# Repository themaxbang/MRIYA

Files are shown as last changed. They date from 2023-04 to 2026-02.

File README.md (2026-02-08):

# MRIYA
**MRIYA** (Ukrainian for «Dream») is a 42-key column-staggered split keyboard based on [Corne Cherry v.3.0.1](https://github.com/foostan/crkbd)

MRIYA

## Features
- Design optimized for wireless
- Updated thumb cluster (inspired by [Jian](https://github.com/KGOH/Jian-Info))
- Reset buttons
- Native nice!view support
- Updated column stagger
- 3DP bumper case (inspired by [Dao Choc BLE](https://github.com/yumagulovrn/dao-choc-ble))
- CNC plates
- BSI-10H Slide Switches
- Molex PicoBlade 1.25mm connectors
- LiPo Battery 301230/301645 support
- No-Solder Spring Headers support
- No LEDs
- Hotswap MX
- ZMK support

## PCB
<table align="center">
    <tr>
        <td align="left">Software</td>
        <td align="left"><a href="https://www.kicad.org/">KiCad 9.0.7 Stable</a></td>
    </tr>
    <tr>
        <td align="left">Silkscreen font</td>
        <td align="left"><a href="https://fonts.google.com/specimen/Roboto">Roboto</a> | <a href="https://fonts.google.com/specimen/Roboto+Condensed">Roboto condensed</a></td>
    </tr>
    <tr>
        <td align="left">Bird logo</td>
        <td align="left"><a href="https://pngtree.com/freepng/minimalist-bird-logo_4124682.html">pngtree.com</a></td>
    </tr>
    <tr>
        <td align="left">PCB Art</td>
        <td align="left"> Olga Rai <a href="https://www.shutterstock.com/g/OlgaRai">Shutterstock</a> | <a href="https://stock.adobe.com/contributor/209778624/olga-rai">Adobe Stock</a></td>
    </tr>
</table>

#### <div align="center">Top<div>
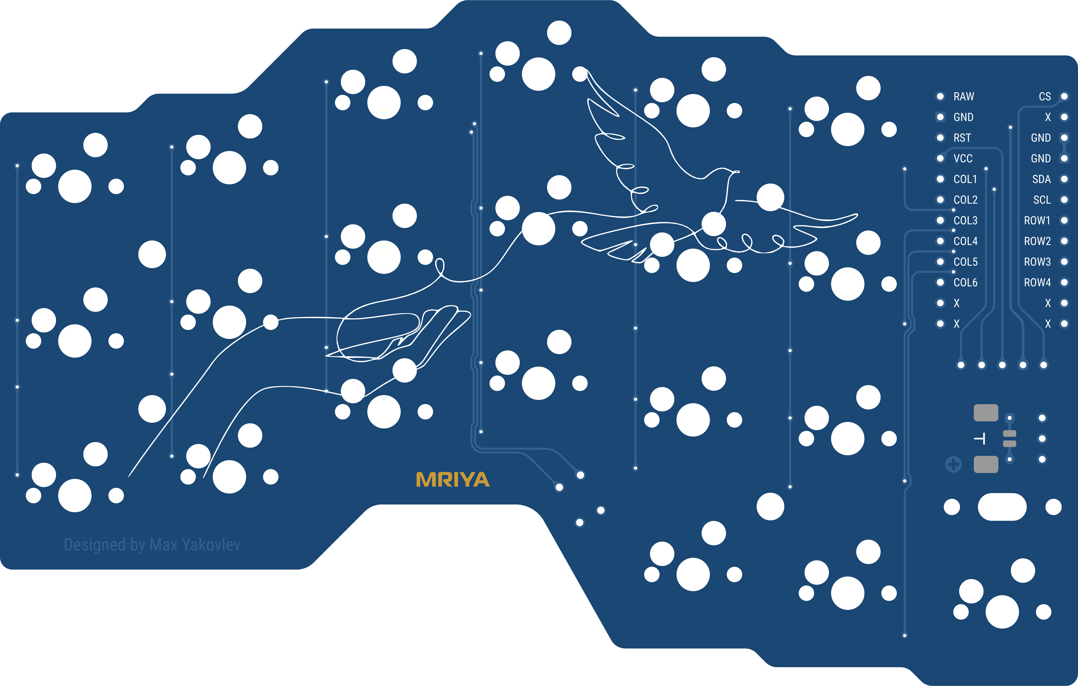
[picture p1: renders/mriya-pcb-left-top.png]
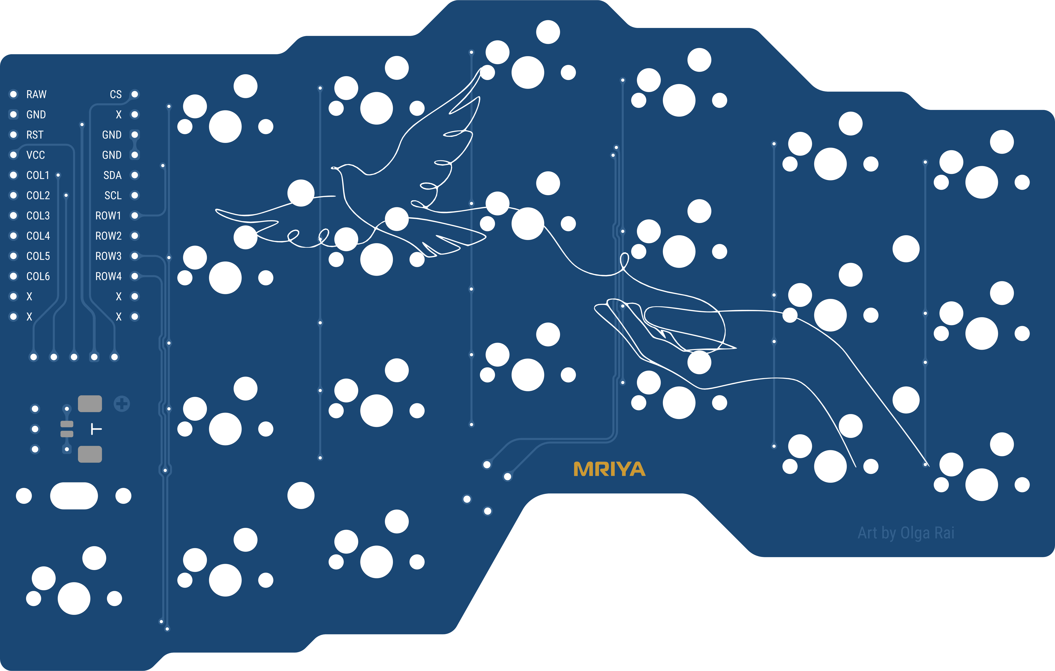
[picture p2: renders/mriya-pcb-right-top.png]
| 
 ---- | -----  

#### <div align="center">Bottom<div>
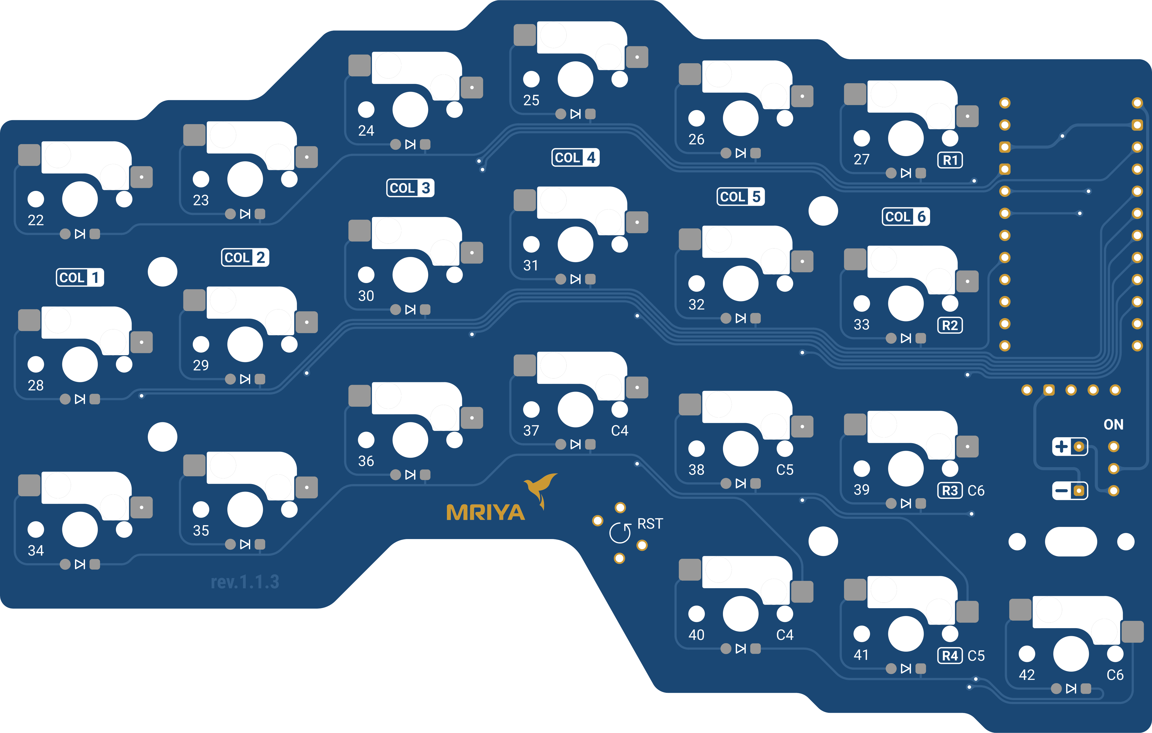
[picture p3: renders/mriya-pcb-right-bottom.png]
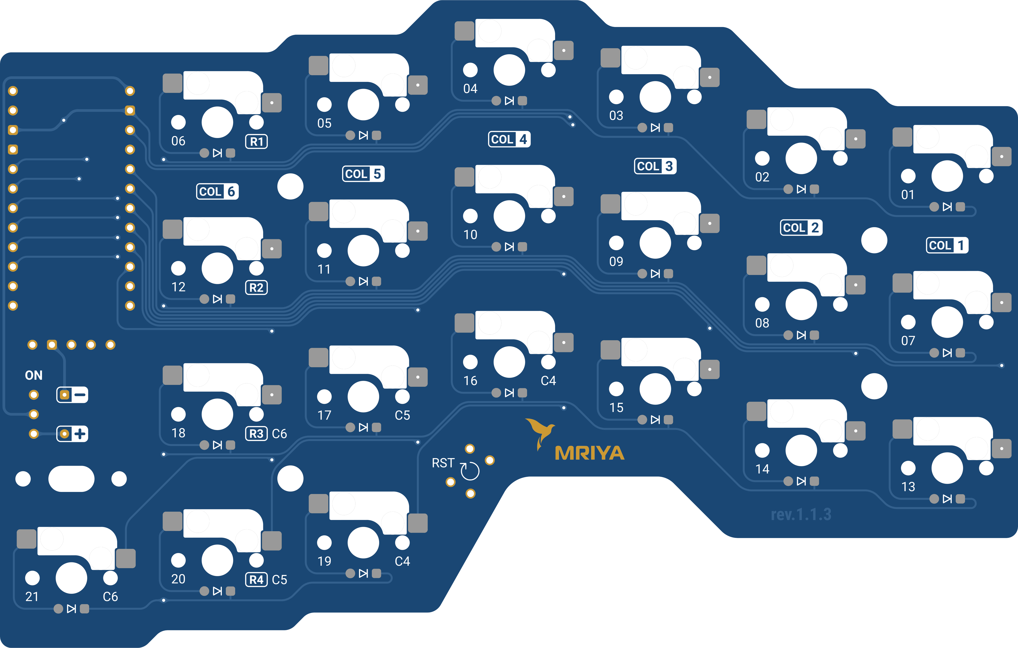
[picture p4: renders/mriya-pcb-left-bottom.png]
|   
 ---- | -----  

## PCB Plates
<table align="center">
    <tr>
        <td align="left">Logo font</td>
        <td align="left"><a href="https://fontbundles.net/integritype-studio/1610789-william-narasi-calligraphy-font">William Narasi</a></td>
    </tr>
</table>

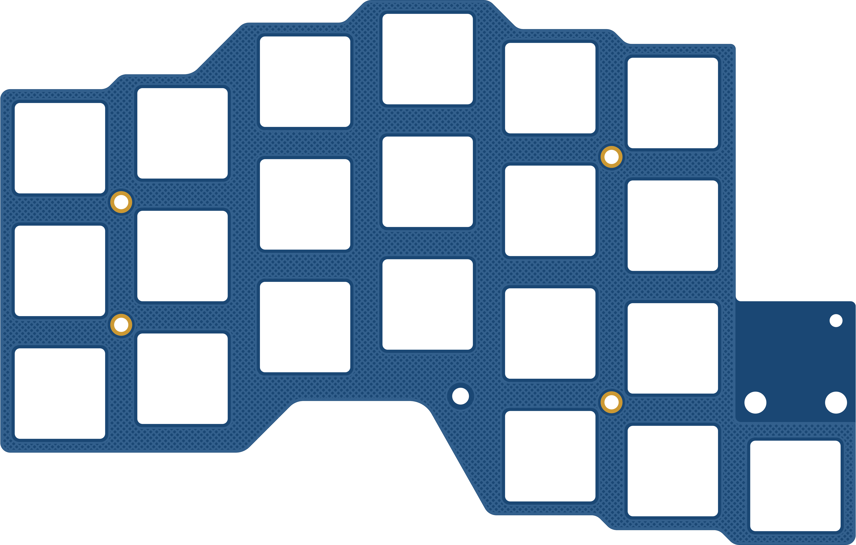
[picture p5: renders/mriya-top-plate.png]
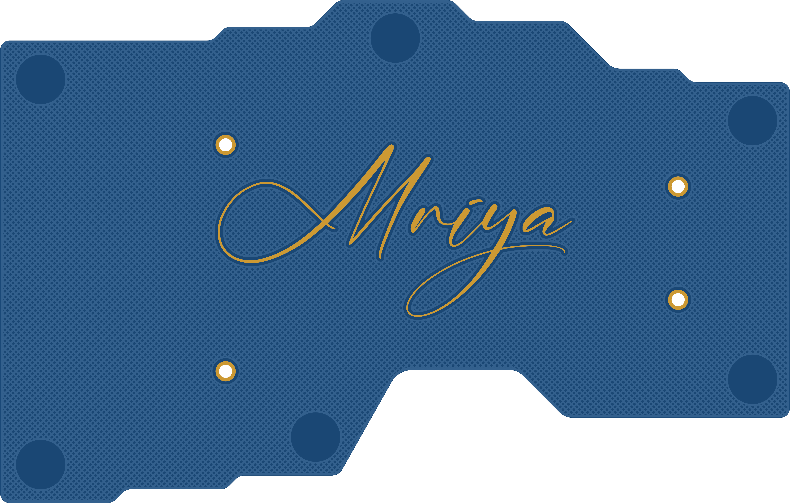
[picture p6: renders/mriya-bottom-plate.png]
|   
 ---- | -----

## 3D Printed Bumper Case
#### <div align="center">FDM<div>
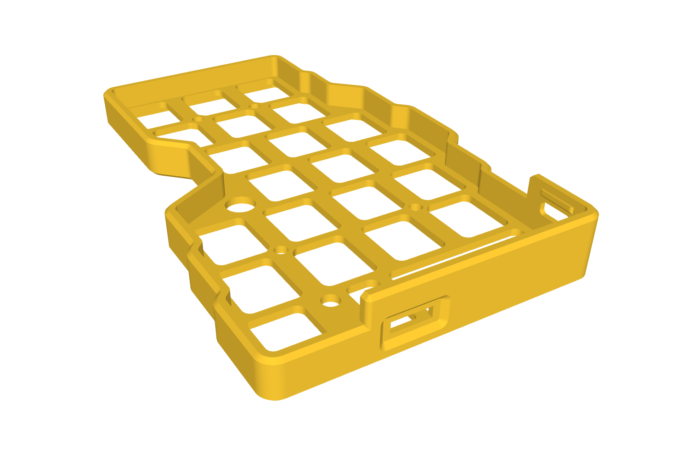
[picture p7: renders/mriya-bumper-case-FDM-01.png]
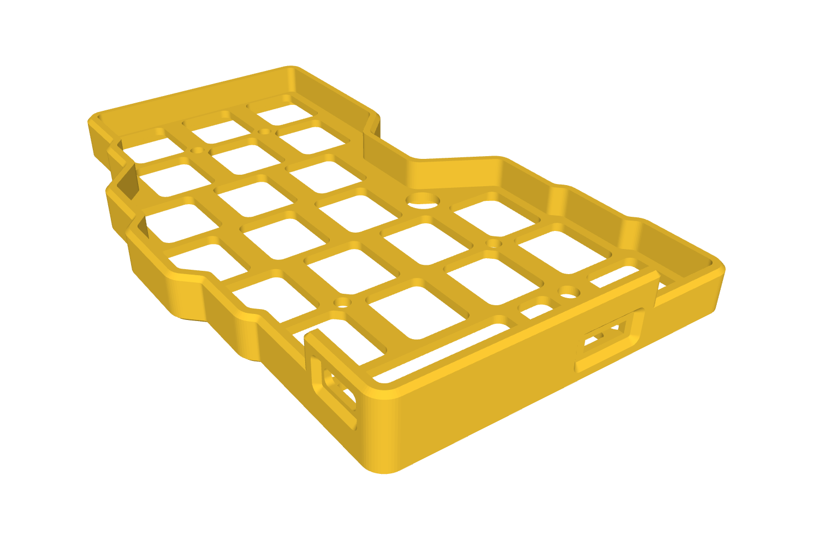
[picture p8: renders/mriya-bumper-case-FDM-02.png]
|
 ---- | -----

## Bill of Materials
Reference|Name|Qty|LCSC|AliExpess
 ------- | ------- | ------- | ------- | ------- 
U1, U2 | Microcontroller: [nRFMicro](https://github.com/joric/nrfmicro) / SuperMini nRF52840 / nice!nano | 2 | --- | [AliExpress](https://aliexpress.com/item/1005006282506884.html?sku_id=12000036599296319)
SW1-SW42 | Kailh Hotswap Socket CPG151101S11 | 42 | [LCSC](https://www.lcsc.com/product-detail/Mechanical-Keyboard-Shaft_span-style-background-color-ff0-Kailh-span-CPG151101S11-16_C5156480.html) | [AliExpress](https://aliexpress.com/item/1005007639688349.html?sku_id=12000041605806628)
D1-D42 | Diode 1N4148W (SOD-123) | 42 | [LCSC](https://www.lcsc.com/product-detail/Switching-Diodes_JSMSEMI-1N4148W_C917030.html) | [AliExpess](https://aliexpress.com/item/1005008224039255.html?sku_id=12000044288109815)
PSW1, PSW2 | Power Switch SUNGMUN BSI-10H | 2 | [LCSC](https://www.lcsc.com/product-detail/Slide-Switches_SM-Switch-BSI-10H_C5775777.html) | [AliExpress](https://aliexpress.com/item/1005006561513178.html?sku_id=12000037678382032)
RSW1, RSW2 | Reset Button TC-1109-C-A (4.5x4.5x**5.5**mm) 4pin DIP | 2 | [LCSC](https://www.lcsc.com/product-detail/Tactile-Switches_XKB-Connectivity-TC-1109-C-A_C561500.html) | [AliExpress](https://aliexpress.com/item/1005001629344310.html?sku_id=12000016890022339)
J1, J2 | Nice!view display [optional] | 2 | --- | [AliExpess](https://aliexpress.com/item/1005007972384358.html?sku_id=12000043094547978)
J3, J4 | Molex PicoBlade 532610271 connector | 2 | [LCSC](https://www.lcsc.com/product-detail/Wire-To-Board-Wire-To-Wire-Connector_MOLEX-532610271_C189700.html) | [AliExpress](https://aliexpress.com/item/1005004425197503.html?sku_id=12000029142536237)
--- | Socket PH5 12pin (Female header) pitch 2.54mm | 4 | --- | [AliExpress](https://aliexpress.com/item/1005006055026707.html?sku_id=12000037525939024)
--- | Socket PH5 5pin (Female header) pitch 2.54mm | 2 | --- | [AliExpress](https://aliexpress.com/item/1005006055026707.html?sku_id=12000037525939018)
--- | LiPo Battery 301230 | 2 | --- | [AliExpress](https://aliexpress.com/item/1005008151618452.html?sku_id=12000044007992383)
--- | LiPo Battery 301645 (Mounts underneath the PCB. During assembly, you must trim the PH5 sockets and power switches legs flush with the PCB using a special template) [optional] | 2 | --- | [AliExpress](https://aliexpress.com/item/32822552643.html?sku_id=64950436890)
--- | Jst Connector 1.25mm Dual Head Wire Cable 2 Pin Female Plug [optional] | 2 | --- | [AliExpress](https://aliexpress.com/item/1005006000774395.html?sku_id=12000035250620558)
--- | Silicone Bumpers 8x2mm (for Classic case or CNC plates) | 12 | --- | [AliExpress](https://aliexpress.com/item/1005005467943079.html?sku_id=12000033199265741)
--- | Silicone Bumpers 8x1.5mm (for FR4 plates) | 12 | --- | [AliExpress](https://aliexpress.com/item/1005002478823169.html?sku_id=12000038015770755)
--- | Brass Round Standoff Spacer Female M2 10mm | 4 | --- | [AliExpress](https://aliexpress.com/item/1005002979083511.html?sku_id=12000023043529034)
--- | Brass Round Standoff Spacer Female M2 7mm | 8 | --- | [AliExpress](https://aliexpress.com/item/1005002979083511.html?sku_id=12000023043529031)
--- | Brass Round Standoff Spacer Female M2 6mm (for Classic case 301230 + FR4 plates) | 8 | --- | [AliExpress](https://aliexpress.com/item/1005002979083511.html?sku_id=12000023043529030)
--- | M3 ABS Nylon Round Standoff Spacer 3.5mm | 12 | --- | [AliExpress](https://aliexpress.com/item/1005004162177818.html?sku_id=12000028239766646)
--- | M3 Black ABS Non-Threaded Hollowed Nylon Spacer 5mm [optional] | 4 | --- | [AliExpress](https://aliexpress.com/item/1005006120526666.html?sku_id=12000035843885709)
--- | M2 Stainless Steel Torx Six-Lobe Ultra Thin Head Screw 4mm | 24 | --- | [AliExpress](https://aliexpress.com/item/1005002461101939.html?sku_id=12000025423430581)
--- | M2 Stainless Steel Torx Head Flat Countersunk Screw 8mm (for Classic case + FDM plates) | 12 | --- | [AliExpress](https://aliexpress.com/item/1005007404555871.html?sku_id=12000040603875540)
--- | M2 Stainless Steel Torx Head Flat Countersunk Screw 5mm (for Classic case + FR4 plates) | 12 | --- | [AliExpress](https://aliexpress.com/item/1005007404555871.html?sku_id=12000040603875538)
--- | M2 Grade 12.9 Insert Torx Screw 5mm (for CNC covers) [optional] | 4 | --- | [AliExpress](https://aliexpress.com/item/4000498337202.html?sku_id=10000002274132371)
--- | М2 (OD 3.2mm) Brass Thread Heat Insert (for FDM plates and covers) length 3mm | 16 | --- | [AliExpress](https://aliexpress.com/item/1005006161392792.html?sku_id=12000036051013760)

## Firmware
You can use any firmware compatible with the Corne keyboard.
[ZMK Config](https://github.com/themaxbang/mriya-zmk-config) for the MRIYA

## Inspiration
- [Corne](https://github.com/foostan/crkbd) | [Corne Ultralight](https://github.com/petejohanson/crkbd/tree/board/corne-ultralight)
- [Jian](https://github.com/KGOH/Jian-Info)
- [Chocofi](https://github.com/pashutk/chocofi) | [Fifi](https://github.com/raychengy/fifi_split_keeb)
- [Dao Choc BLE](https://github.com/yumagulovrn/dao-choc-ble)

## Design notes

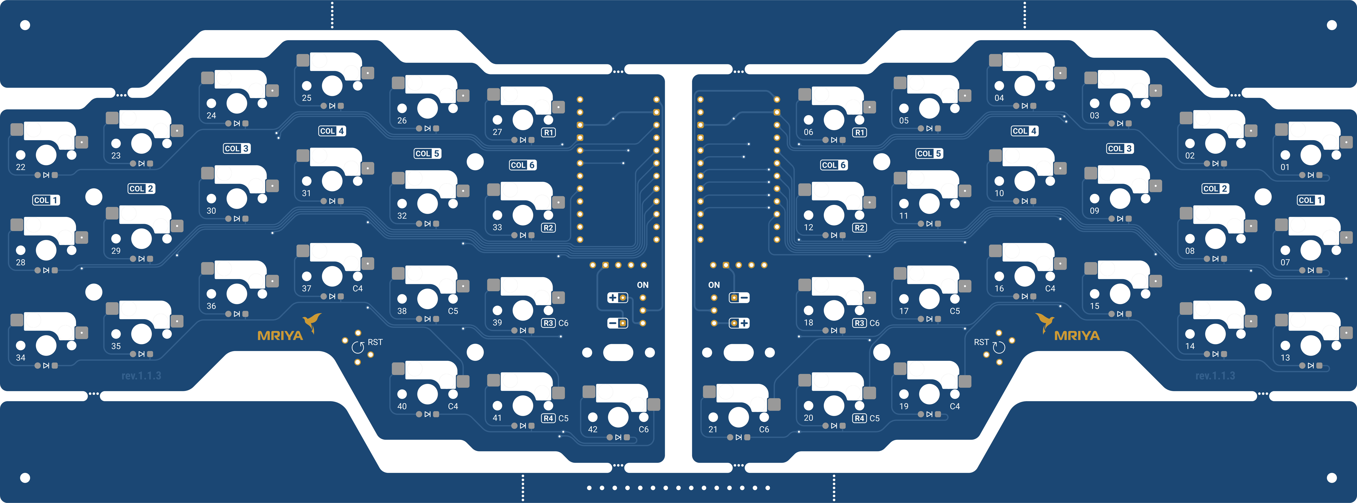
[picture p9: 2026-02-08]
renders/mriya-pcb-bottom.png

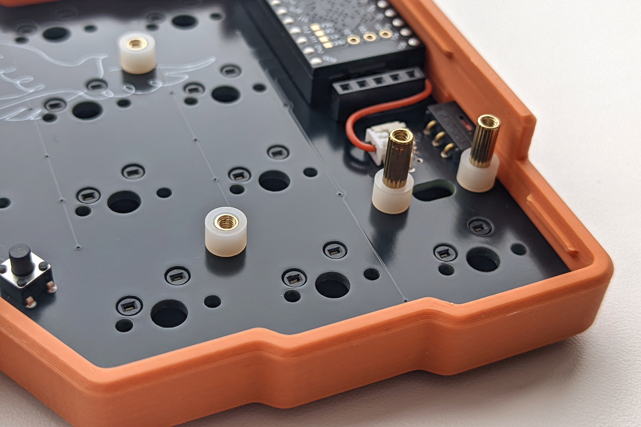
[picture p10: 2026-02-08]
pictures/mriya_05.jpeg

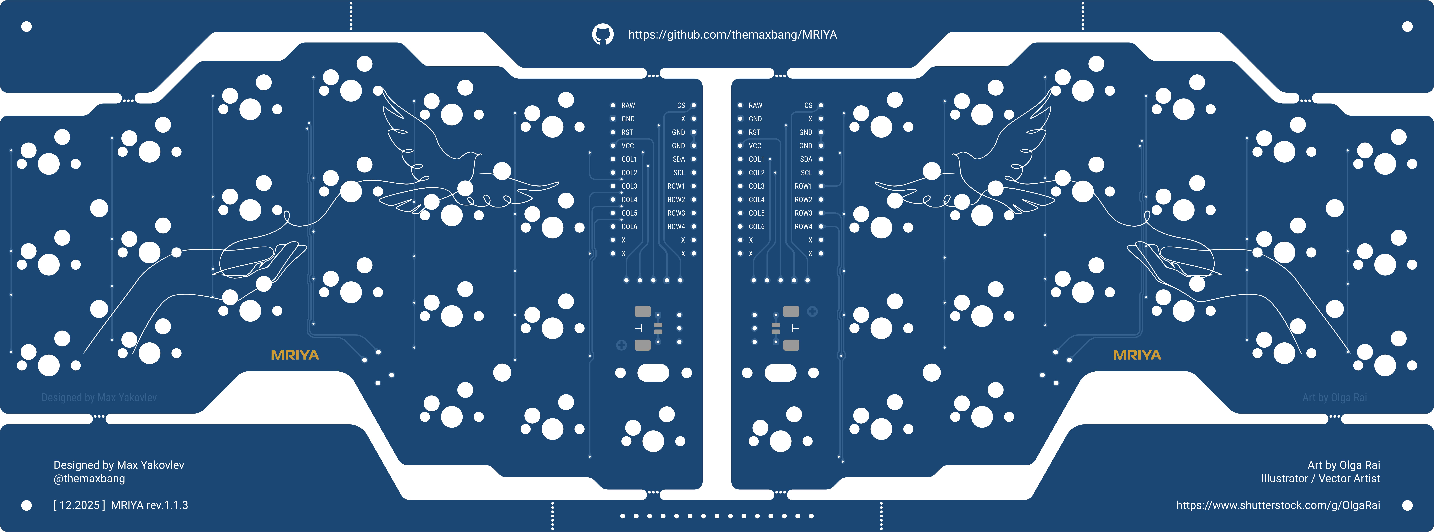
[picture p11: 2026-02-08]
renders/mriya-pcb-top.png

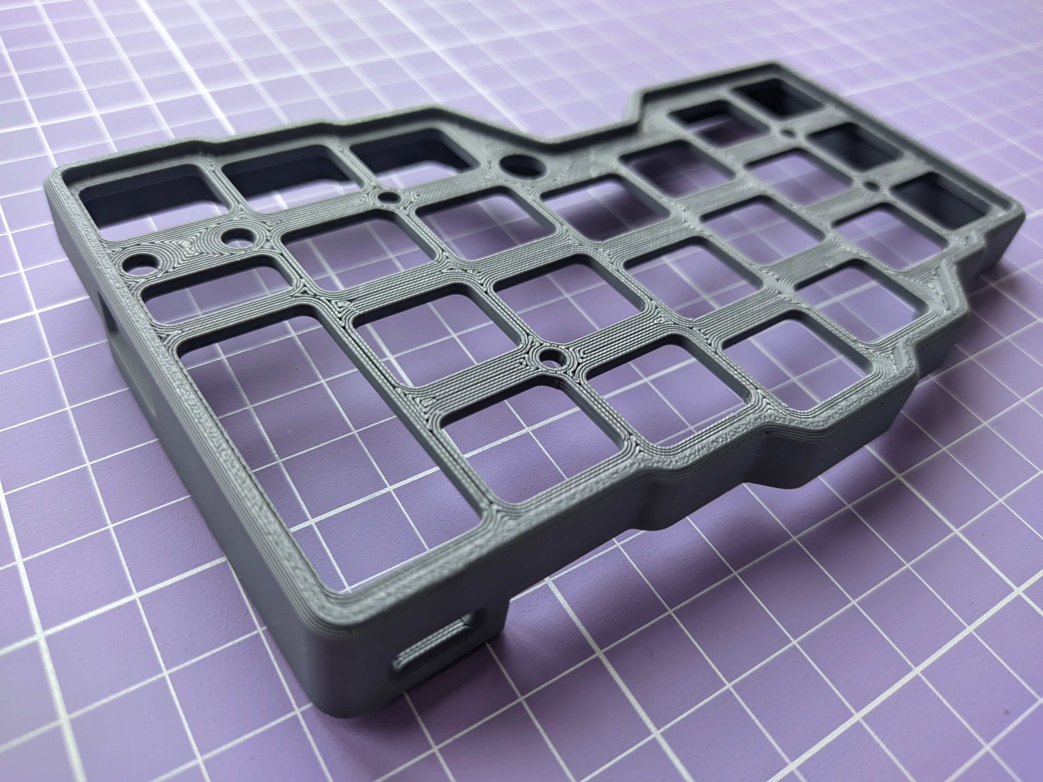
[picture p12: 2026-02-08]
pictures/mriya_15.jpeg

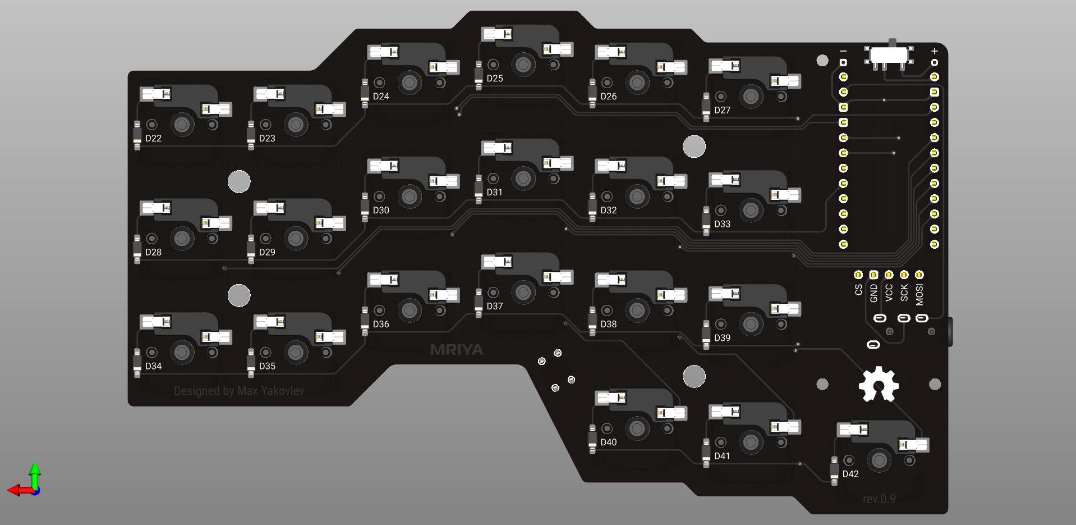
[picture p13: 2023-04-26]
renders/mriya-right-bottom.png

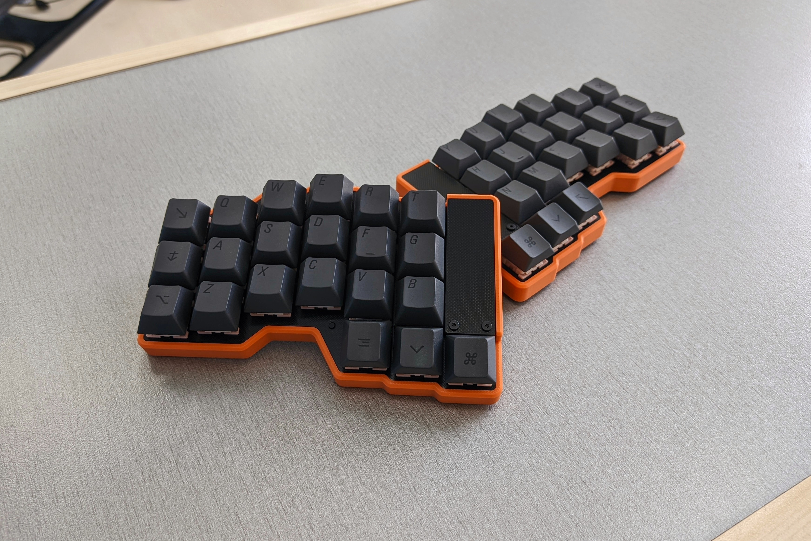
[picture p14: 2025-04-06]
pictures/mriya_01.jpeg

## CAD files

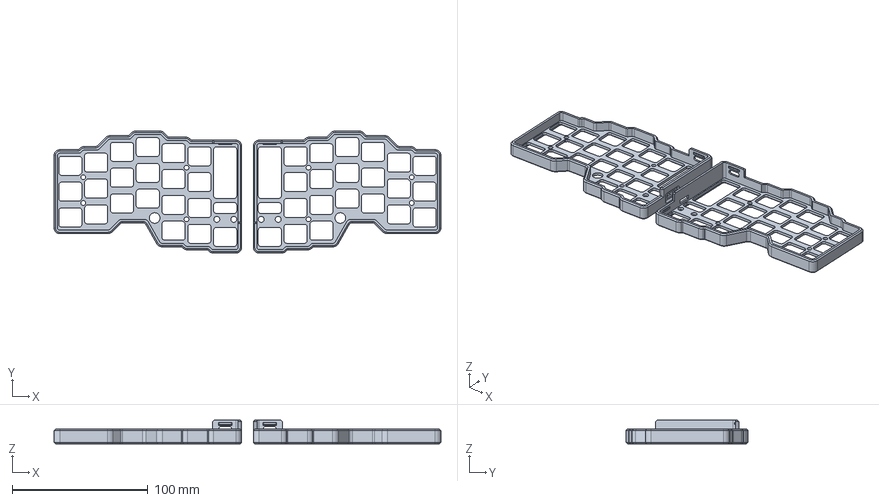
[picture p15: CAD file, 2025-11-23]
case/3DP/01 bumper case/FDM/mriya-bumper-fdm-v1.16.step
284.8 x 89.9 x 17.3 mm

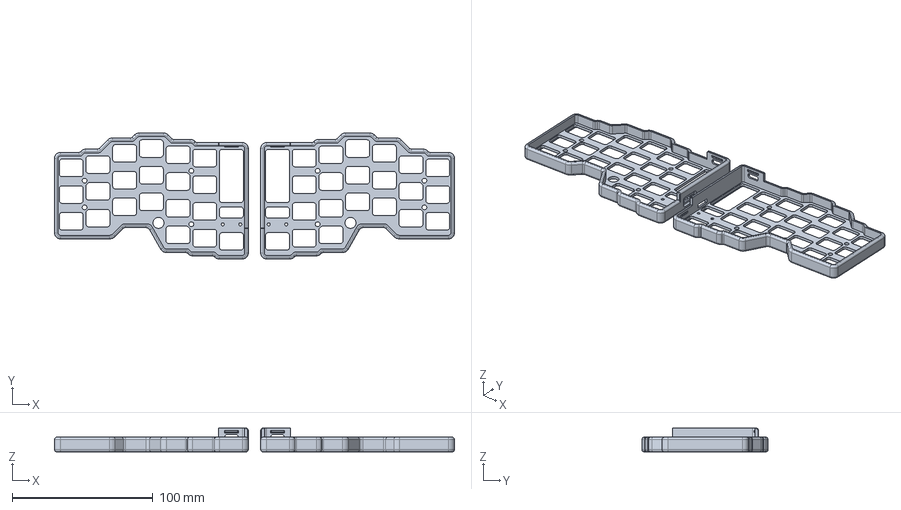
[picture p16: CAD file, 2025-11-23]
case/3DP/01 bumper case/MJF (not tested)/mriya-bumper-mjf-v1.17.step
284.6 x 89.7 x 17.0 mm

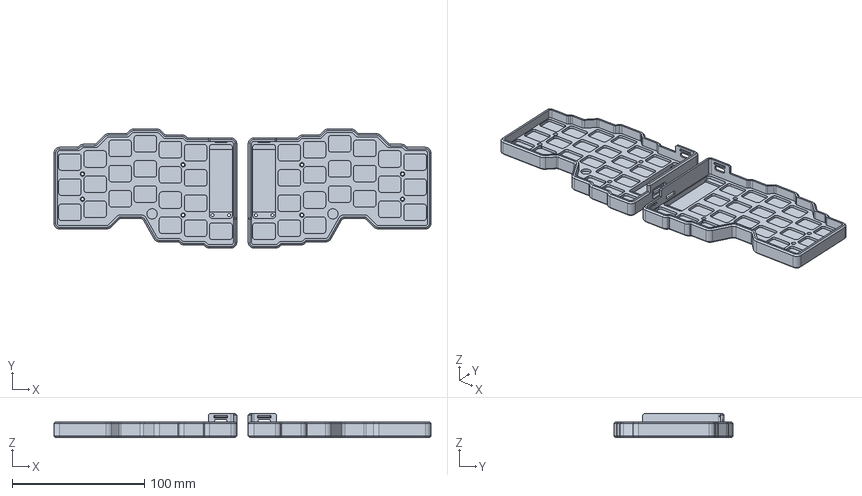
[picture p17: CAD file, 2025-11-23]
case/3DP/02 classic case/FDM/301645 battery support/mriya-classic-fdm-301645-v1.01.step
284.8 x 89.9 x 18.5 mm

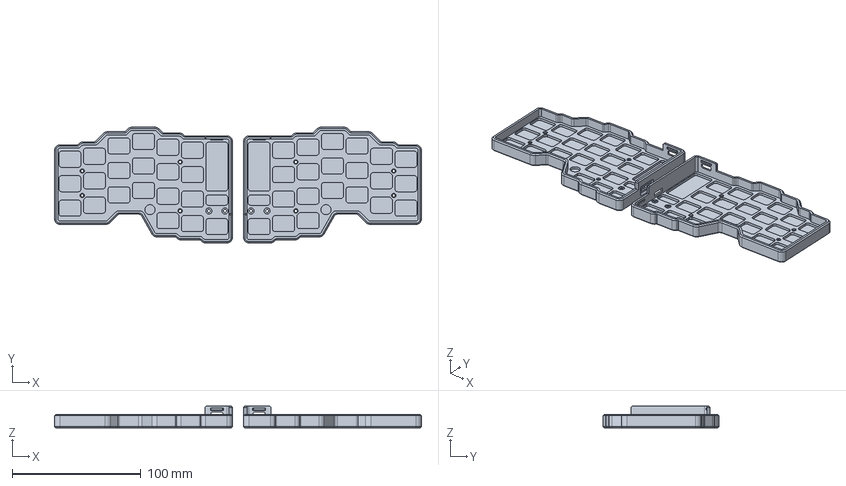
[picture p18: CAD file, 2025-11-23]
case/3DP/02 classic case/FDM/mriya-classic-fdm-v1.13.step
284.8 x 89.9 x 17.0 mm

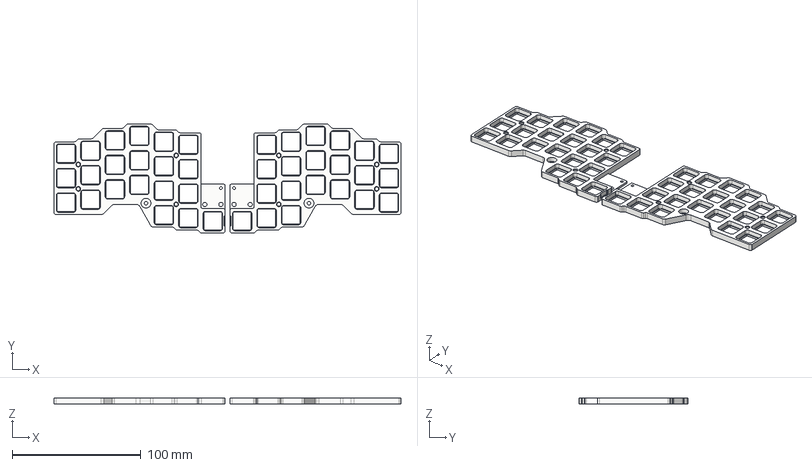
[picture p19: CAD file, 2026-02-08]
case/3DP/03 top plate/FDM/mriya-top-plate-fdm-v1.03.step
269.5 x 84.6 x 5.00 mm

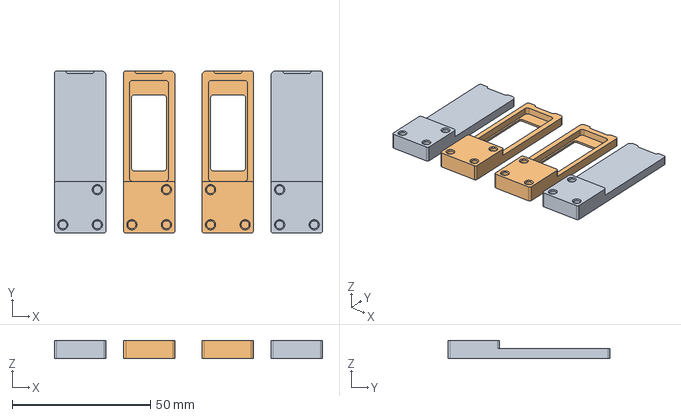
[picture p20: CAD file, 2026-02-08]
case/3DP/04 display mcu cover/FDM/mriya-display-mcu-cover-fdm-v1.03.step
97.0 x 58.7 x 6.60 mm

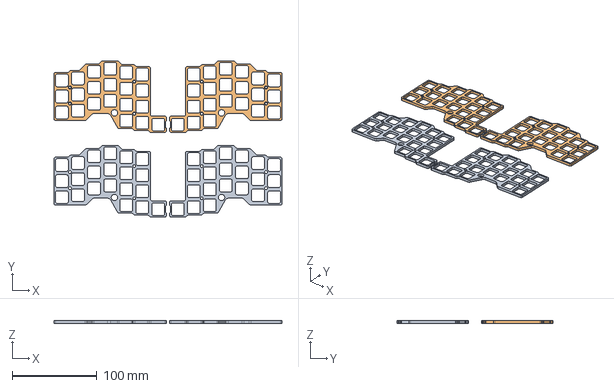
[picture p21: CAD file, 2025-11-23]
case/3DP/05 spacer/FDM/mriya-spacer-fdm-v.1.02.step
269.5 x 184.6 x 3.40 mm

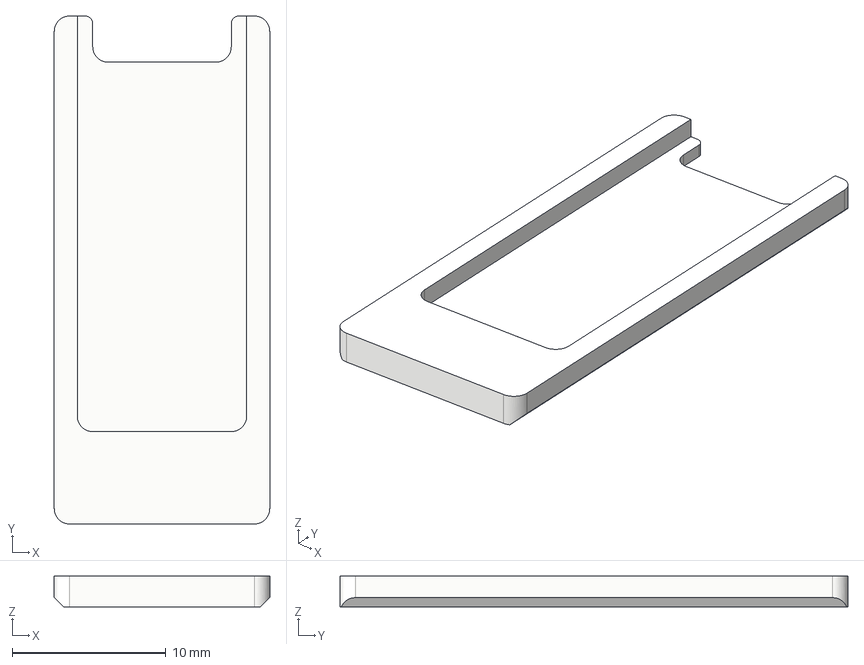
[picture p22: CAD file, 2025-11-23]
case/3DP/06 niceview holder/FDM/mriya-niceview-holder-fdm-v1.01.step
14.0 x 33.0 x 2.00 mm

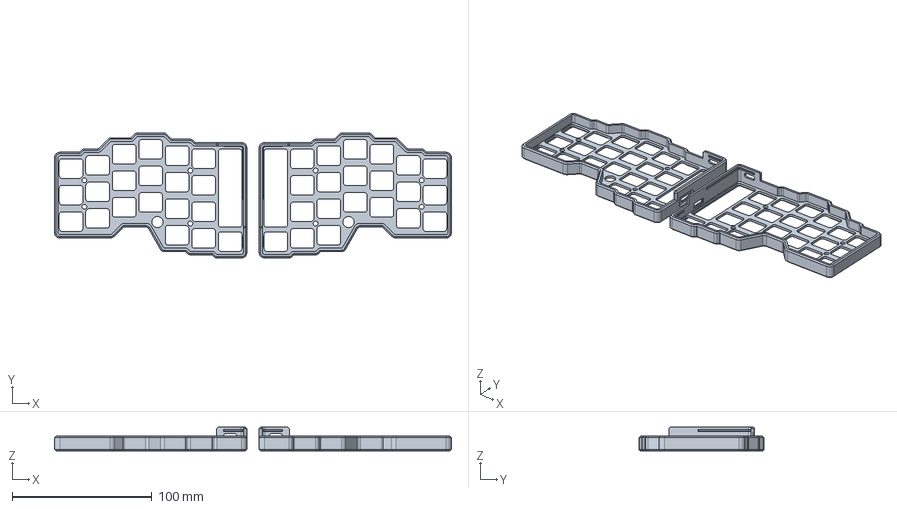
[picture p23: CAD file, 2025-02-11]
case/3DP/bumper case/FDM/mriya-bumper-fdm-v1.13.step
284.6 x 89.7 x 17.0 mm

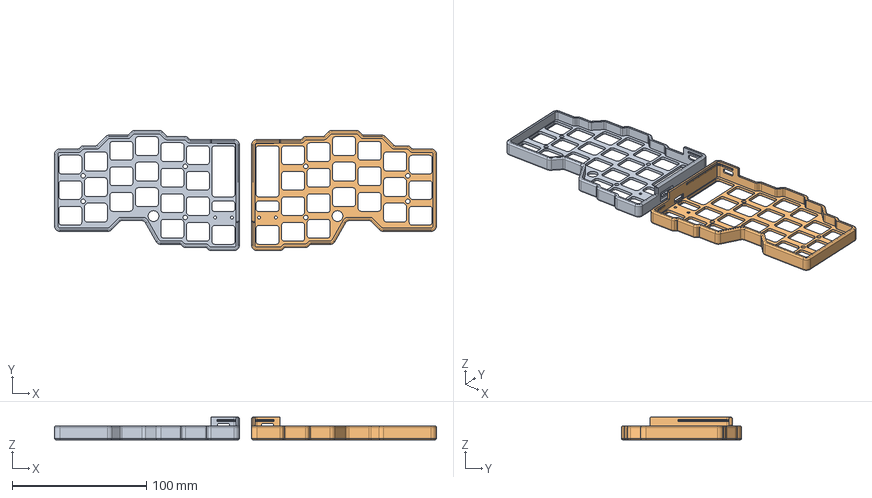
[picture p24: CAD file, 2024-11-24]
case/3DP/bumper/SLA/mriya-bumper-sla-v1.16.step
284.4 x 89.5 x 17.0 mm

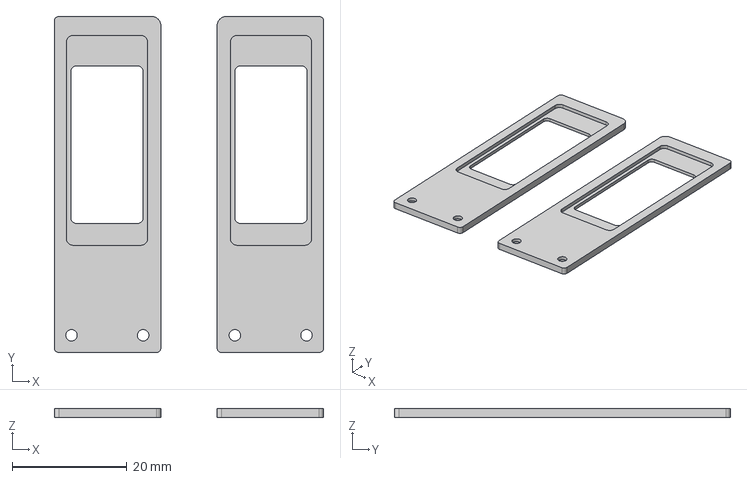
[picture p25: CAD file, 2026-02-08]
case/CNC (not tested)/01 display cover/mriya-cnc-display-cover-v1.01.step
47.0 x 58.6 x 1.50 mm

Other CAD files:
case/3DP/01 bumper case/SLA (not tested)/mriya-bumper-sla-v1.19.step
case/3DP/bumper case/MJF/mriya-bumper-mjf-v1.15.step
case/3DP/bumper case/SLA/mriya-bumper-sla-v1.12.step
case/3DP/bumper/FDM/mriya-bumper-fdm-v1.12.step
case/3DP/bumper/MJF/mriya-bumper-mjf-v1.13.step
case/3DP/classic case/FDM/mriya-classic-fdm-v1.04.step
case/3DP/classic/FDM/mriya-classic-fdm-v1.10.step
case/3DP/01 bumper case/FDM/mriya-bumper-fdm-v1.16.f3d
case/3DP/01 bumper case/MJF (not tested)/mriya-bumper-mjf-v1.17.f3d
case/3DP/01 bumper case/SLA (not tested)/mriya-bumper-sla-v1.19.f3d
case/3DP/02 classic case/FDM/301645 battery support/mriya-classic-fdm-301645-v1.01.f3d
case/3DP/02 classic case/FDM/mriya-classic-fdm-v1.13.f3d
case/3DP/03 top plate/FDM/mriya-top-plate-fdm-v1.03.f3d
case/3DP/04 display mcu cover/FDM/mriya-display-mcu-cover-fdm-v1.03.f3d
case/3DP/05 spacer/FDM/mriya-spacer-fdm-v.1.02.f3d
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

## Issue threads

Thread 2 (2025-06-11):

[PCB Mod] Multi-switch Compatibility Mod

Eloy98, 2025-06-11:
As a ZMK split keyboard enthusiast, I was truly impressed by your excellent case design. Inspired by your repository files, I've developed a new PCB featuring:
✨ **Triple switch compatibility** - Native support for MX, Choc V1/V2, and Gateron Low-Profile switches
🔧 **Precise adaptation** - Fully maintains mounting points

However, **I lack 3D modeling skills** and wanted to ask:
🙋 Would you have capacity to develop a low-profile case version?
- I can provide:
  ✅ Height measurements for LP switches
  ✅ Physical PCB prototypes for testing
  ✅ Collaborative validation support

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

themaxbang, 2025-06-18:
Wow, you did a great job!

But unfortunately, I don't plan to release a keyboard for low-profile switches. There are many things to think about, for example, the reset button is not suitable because of the height.

Also, I don't have a 3D printer, without it it's hard to develop cases. I hope to publish the project soon and someone from the community will be able to help you.

There are several projects with a similar layout:
- [fEnki](https://github.com/aroum/fEnki)
- [KOMETA](https://github.com/inpudiy/KOMETA)

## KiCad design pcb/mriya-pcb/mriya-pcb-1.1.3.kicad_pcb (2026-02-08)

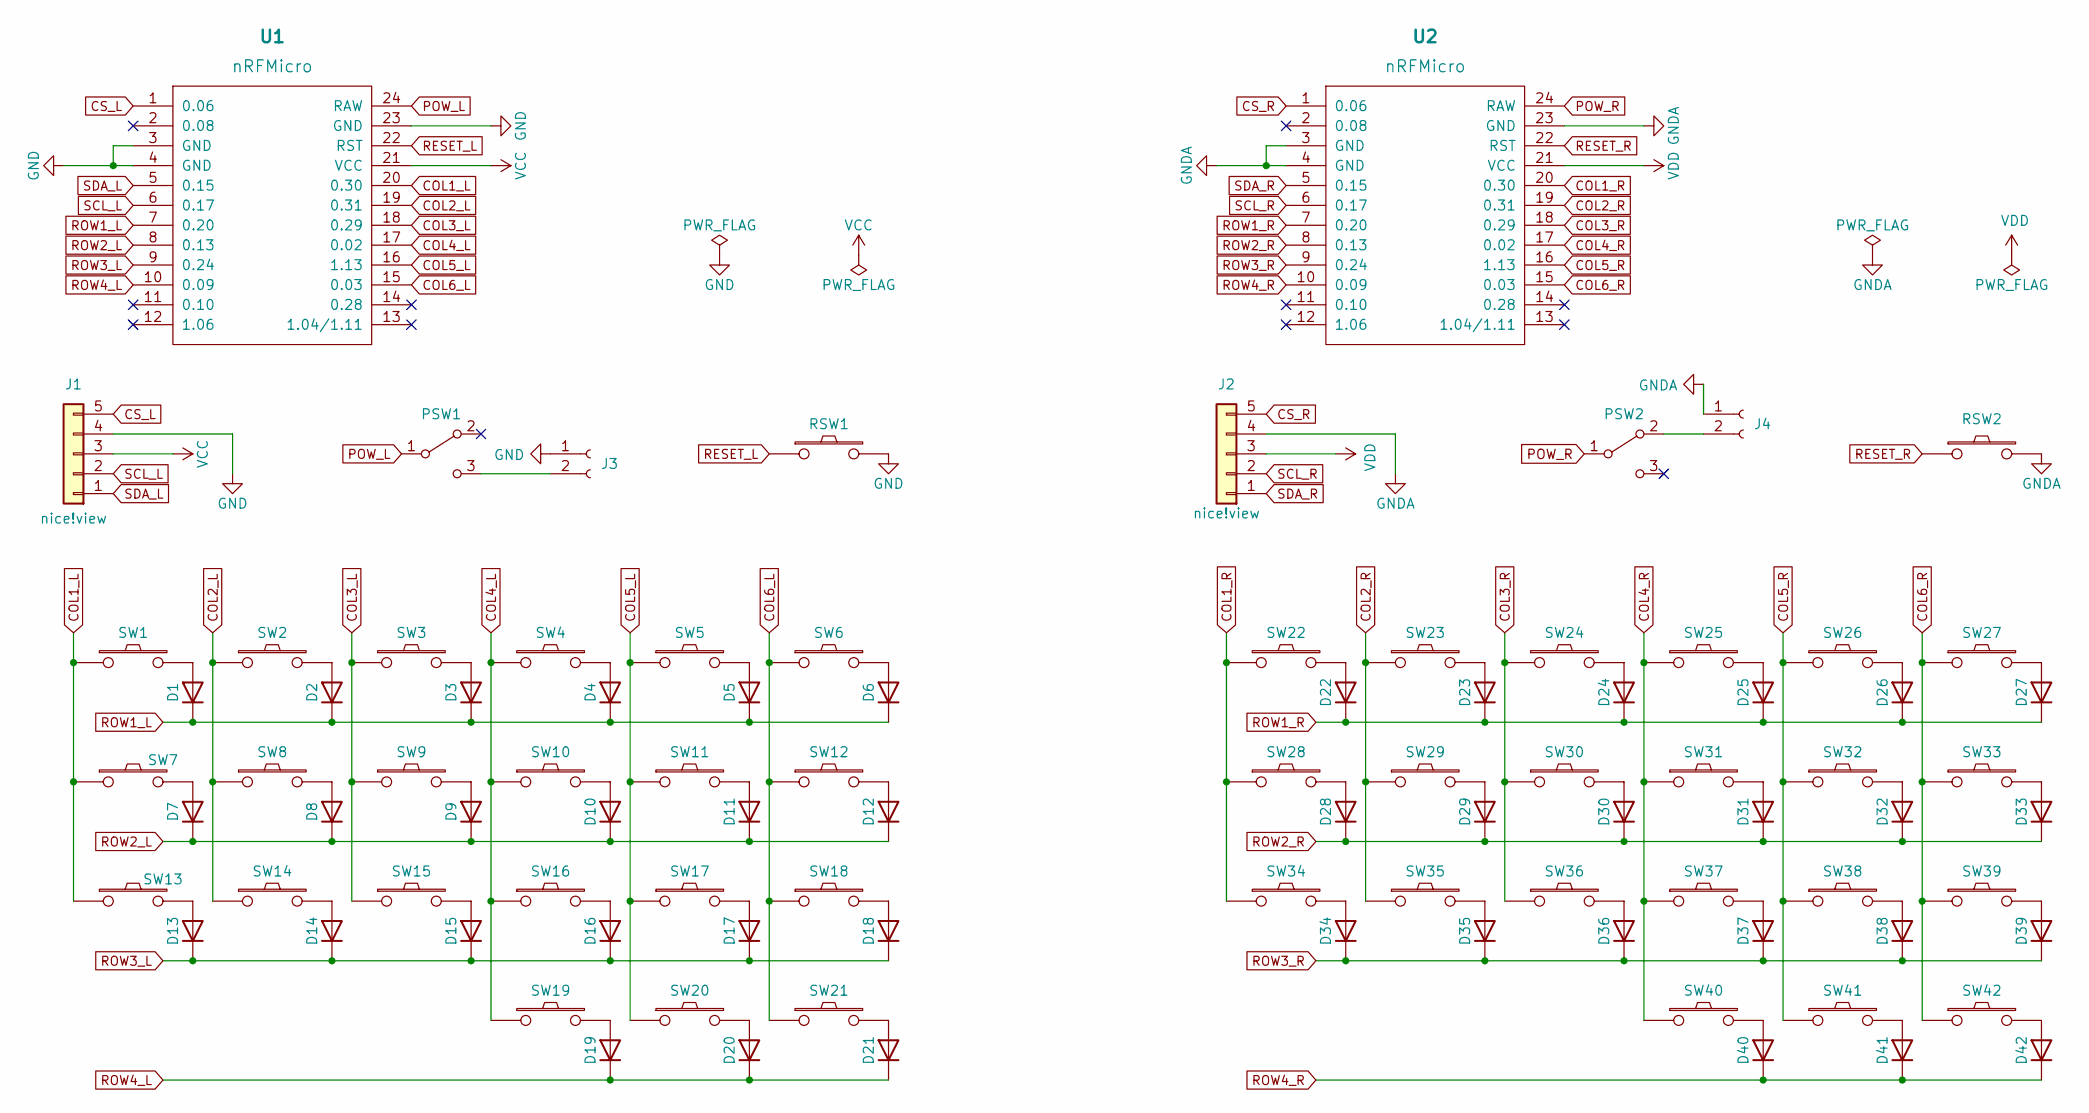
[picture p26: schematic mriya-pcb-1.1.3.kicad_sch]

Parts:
D1, D2, D3, D4, D5, D6, D7, D8, D9, D10, D11, D12, D13, D14, D15, D16, D17, D18, D19, D20, D21, D22, D23, D24, D25, D26, D27, D28, D29, D30, D31, D32, D33, D34, D35, D36, D37, D38, D39, D40, D41, D42: D; 1N4148_T4
J1, J2: nice!view; nice_view
J3, J4: JST; Molex_532610271
PSW1, PSW2: SW_SPDT; BSI-10h
RSW1, RSW2: RSW; RSW_4.5x4.5_left
SW1, SW2, SW3, SW4, SW5, SW6, SW7, SW8, SW9, SW10, SW11, SW12, SW13, SW14, SW15, SW16, SW17, SW18, SW19, SW20, SW21, SW22, SW23, SW24, SW25, SW26, SW27, SW28, SW29, SW30, SW31, SW32, SW33, SW34, SW35, SW36, SW37, SW38, SW39, SW40, SW41, SW42: SW_PUSH; CherryMX_Hotswap_1U
U1, U2: nRFMicro; nRFMicro_v2

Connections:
COL1_L: SW1.1, SW7.1, SW13.1, U1.20 (0.30)
COL1_R: SW22.1, SW28.1, SW34.1, U2.20 (0.30)
COL2_L: SW2.1, SW8.1, SW14.1, U1.19 (0.31)
COL2_R: SW23.1, SW29.1, SW35.1, U2.19 (0.31)
COL3_L: SW3.1, SW9.1, SW15.1, U1.18 (0.29)
COL3_R: SW24.1, SW30.1, SW36.1, U2.18 (0.29)
COL4_L: SW4.1, SW10.1, SW16.1, SW19.1, U1.17 (0.02)
COL4_R: SW25.1, SW31.1, SW37.1, SW40.1, U2.17 (0.02)
COL5_L: SW5.1, SW11.1, SW17.1, SW20.1, U1.16 (1.13)
COL5_R: SW26.1, SW32.1, SW38.1, SW41.1, U2.16 (1.13)
COL6_L: SW6.1, SW12.1, SW18.1, SW21.1, U1.15 (0.03)
COL6_R: SW27.1, SW33.1, SW39.1, SW42.1, U2.15 (0.03)
CS_L: J1.5, U1.1 (0.06)
CS_R: J2.5, U2.1 (0.06)
GND: J1.4, J3.1 (Pin_2), RSW1.2, U1.3 (GND), U1.4 (GND), U1.23 (GND)
GNDA: J2.4, J4.1 (Pin_2), RSW2.2, U2.3 (GND), U2.4 (GND), U2.23 (GND)
unnamed: D1.2 (A), SW1.2
unnamed: D2.2 (A), SW2.2
unnamed: D3.2 (A), SW3.2
unnamed: D4.2 (A), SW4.2
unnamed: D5.2 (A), SW5.2
unnamed: D6.2 (A), SW6.2
unnamed: D7.2 (A), SW7.2
unnamed: D8.2 (A), SW8.2
unnamed: D9.2 (A), SW9.2
unnamed: D10.2 (A), SW10.2
unnamed: D11.2 (A), SW11.2
unnamed: D12.2 (A), SW12.2
unnamed: D13.2 (A), SW13.2
unnamed: D14.2 (A), SW14.2
unnamed: D15.2 (A), SW15.2
unnamed: D16.2 (A), SW16.2
unnamed: D17.2 (A), SW17.2
unnamed: D18.2 (A), SW18.2
unnamed: D19.2 (A), SW19.2
unnamed: D20.2 (A), SW20.2
unnamed: D21.2 (A), SW21.2
unnamed: D22.2 (A), SW22.2
unnamed: D23.2 (A), SW23.2
unnamed: D24.2 (A), SW24.2
unnamed: D25.2 (A), SW25.2
unnamed: D26.2 (A), SW26.2
unnamed: D27.2 (A), SW27.2
unnamed: D28.2 (A), SW28.2
unnamed: D29.2 (A), SW29.2
unnamed: D30.2 (A), SW30.2
unnamed: D31.2 (A), SW31.2
unnamed: D32.2 (A), SW32.2
unnamed: D33.2 (A), SW33.2
unnamed: D34.2 (A), SW34.2
unnamed: D35.2 (A), SW35.2
unnamed: D36.2 (A), SW36.2
unnamed: D37.2 (A), SW37.2
unnamed: D38.2 (A), SW38.2
unnamed: D39.2 (A), SW39.2
unnamed: D40.2 (A), SW40.2
unnamed: D41.2 (A), SW41.2
unnamed: D42.2 (A), SW42.2
unnamed: J3.2 (Pin_1), PSW1.3 (C)
unnamed: J4.2 (Pin_1), PSW2.2 (A)
POW_L: PSW1.1 (B), U1.24 (RAW)
POW_R: PSW2.1 (B), U2.24 (RAW)
RESET_L: RSW1.1, U1.22 (RST)
RESET_R: RSW2.1, U2.22 (RST)
ROW1_L: D1.1 (K), D2.1 (K), D3.1 (K), D4.1 (K), D5.1 (K), D6.1 (K), U1.7 (0.20)
ROW1_R: D22.1 (K), D23.1 (K), D24.1 (K), D25.1 (K), D26.1 (K), D27.1 (K), U2.7 (0.20)
ROW2_L: D7.1 (K), D8.1 (K), D9.1 (K), D10.1 (K), D11.1 (K), D12.1 (K), U1.8 (0.13)
ROW2_R: D28.1 (K), D29.1 (K), D30.1 (K), D31.1 (K), D32.1 (K), D33.1 (K), U2.8 (0.13)
ROW3_L: D13.1 (K), D14.1 (K), D15.1 (K), D16.1 (K), D17.1 (K), D18.1 (K), U1.9 (0.24)
ROW3_R: D34.1 (K), D35.1 (K), D36.1 (K), D37.1 (K), D38.1 (K), D39.1 (K), U2.9 (0.24)
ROW4_L: D19.1 (K), D20.1 (K), D21.1 (K), U1.10 (0.09)
ROW4_R: D40.1 (K), D41.1 (K), D42.1 (K), U2.10 (0.09)
SCL_L: J1.2, U1.6 (0.17)
SCL_R: J2.2, U2.6 (0.17)
SDA_L: J1.1, U1.5 (0.15)
SDA_R: J2.1, U2.5 (0.15)
VCC: J1.3, U1.21 (VCC)
VDD: J2.3, U2.21 (VCC)

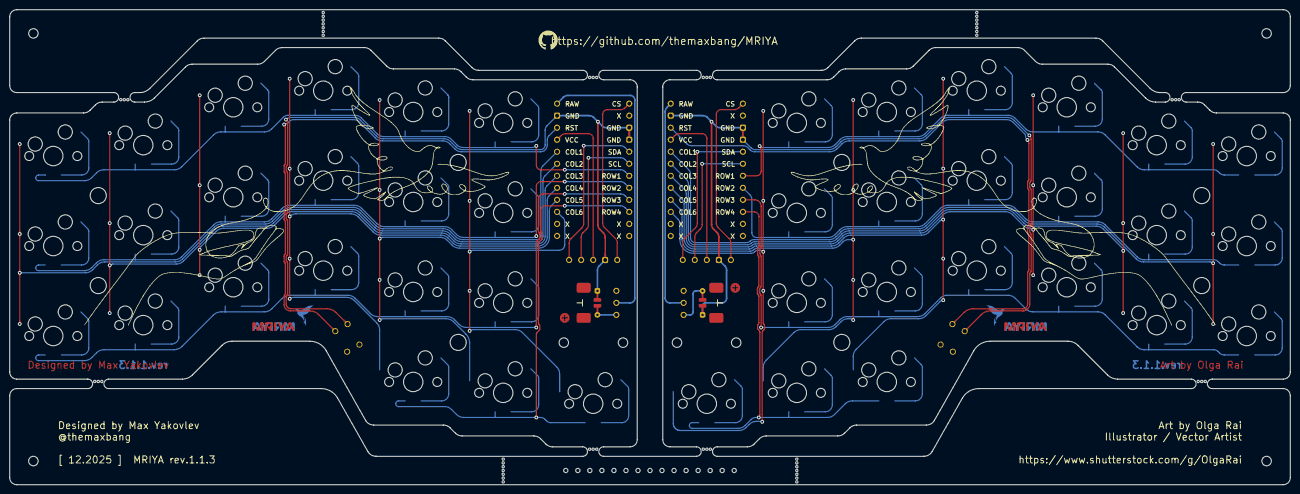
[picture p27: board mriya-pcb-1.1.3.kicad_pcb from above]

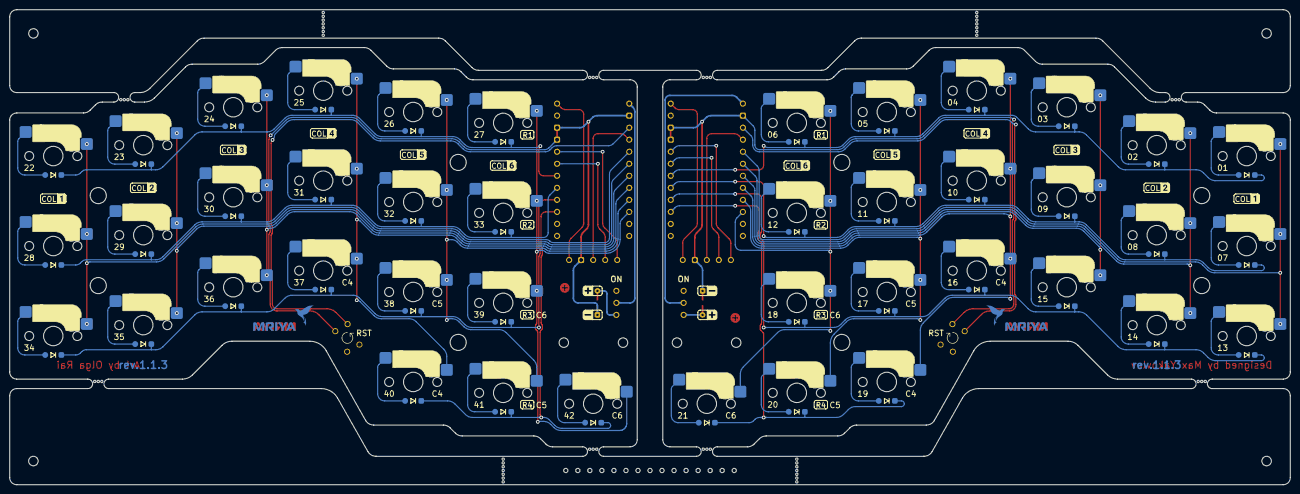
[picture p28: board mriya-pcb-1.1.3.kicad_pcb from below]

Board: 2 copper layers, 270.4 x 100.3 mm, 140 parts (46 on the bottom side), 78 nets.

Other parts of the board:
Bird_Hand_Left: ART; Bird_Hand_Left
Bird_Hand_Right: ART; Bird_Hand_Right
Bird_Logo_B.Cu_Left: LOGO; Bird_Logo_B.Cu_Left
Bird_Logo_B.Cu_Right: LOGO; Bird_Logo_B.Cu_Right
Bird_Logo_B.Mask_Left: LOGO; Bird_Logo_B.Mask_Left
Bird_Logo_B.Mask_Right: LOGO; Bird_Logo_B.Mask_Right
H: Holes 0.9mm; Сutting_template
H1, H2, H11, H12: Hole 2mm; Hole_2mm
H3, H4, H5, H6, H7, H8, H9, H10: Hole 3.4mm; Hole_3.4mm
LOGO: LOGO; GitHub_logo
MB1, MB2, MB3, MB4: MB; Mouse_Bite
MB-2mm-1, MB-2mm-2, MB-2mm-3, MB-2mm-4, MB-2mm-5, MB-2mm-6, MB-2mm-7, MB-2mm-8: MB; Mouse_Bite_2mm_v1
MH1, MH2, MH3, MH4: MountingHole 2mm; Mounting_Hole_2mm
MRIYA_Logo_B.Cu, MRIYA_Logo_B.Cu#2: LOGO; Mriya_Logo_F.Cu
MRIYA_Logo_B.Mask, MRIYA_Logo_B.Mask#2: LOGO; Mriya_Logo_F.Mask
MRIYA_Logo_F.Cu, MRIYA_Logo_F.Cu#2: LOGO; Mriya_Logo_F.Cu
MRIYA_Logo_F.Mask, MRIYA_Logo_F.Mask#2: LOGO; Mriya_Logo_F.Mask
OH1, OH2: Oval Hole; Oval_Hole

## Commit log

2023-04-26 added kicad files
    [mriya-bottom-plate-B_Mask.gbs, mriya-bottom-plate-B_Paste.gbp, mriya-bottom-plate-B_Silkscreen.gbo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]
2023-04-29 updated references
    [mriya-left.kicad_pcb, mriya-left.kicad_sch, mriya-right.kicad_pcb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]
2024-01-30 update redme
    [mriya-bottom-plate-B_Mask.gbs, mriya-bottom-plate-B_Paste.gbp, mriya-bottom-plate-B_Silkscreen.gbo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]
2024-07-14 added a 3DP Case
    [mriya-bumper-sla-left-v1.0.0.stl, mriya-bumper-sla-right-v1.0.0.stl, mriya-bumper-sla-v1.0.0.f3d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]
2024-07-21 update 3DP case
    [mriya-bumper-sla-left-v1.0.0.stl, mriya-bumper-sla-left-v1.1.stl, mriya-bumper-sla-right-v1.0.0.stl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]
2024-08-03 update 3DP cases
    [mriya-bumper-fdm-left-v1.02.stl, mriya-bumper-fdm-right-v1.02.stl, mriya-bumper-fdm-v1.02.f3d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]
2024-08-03 update SLA case
    [mriya-bumper-sla-left-v1.04.stl, mriya-bumper-sla-left-v1.05.stl, mriya-bumper-sla-right-v1.04.stl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]
2024-08-14 update FDM case
    [mriya-bumper-fdm-left-v1.02.stl, mriya-bumper-fdm-left-v1.03.stl, mriya-bumper-fdm-right-v1.02.stl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]
2024-08-15 update cases
    [mriya-bumper-fdm-left-v1.04.stl, mriya-bumper-fdm-left-v1.05.stl, mriya-bumper-fdm-right-v1.04.stl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]
2024-08-18 update MJF case
    [mriya-bumper-mjf-left-v1.01.stl, mriya-bumper-mjf-left-v1.02.stl, mriya-bumper-mjf-right-v1.01.stl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]
2024-08-18 update FDM bumper case
    [mriya-bumper-fdm-left-v1.05.stl, mriya-bumper-fdm-left-v1.06.stl, mriya-bumper-fdm-right-v1.05.stl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]
2024-08-18 update SLA and MJF cases
    [mriya-bumper-mjf-left-v1.02.stl, mriya-bumper-mjf-right-v1.02.stl, mriya-bumper-mjf-v1.02.f3d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]
2024-08-22 update FDM cases
    [mriya-bumper-fdm-left-v1.06.stl, mriya-bumper-fdm-left-v1.07.stl, mriya-bumper-fdm-right-v1.06.stl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]
2024-08-22 update .stl files
    [mriya-bumper-fdm-left-v1.07.stl, mriya-bumper-fdm-right-v1.07.stl, mriya-bumper-mjf-left-v1.02.stl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]
2024-08-28 update SLA&MJF cases
    [mriya-bumper-mjf-left-v1.02.stl, mriya-bumper-mjf-left-v1.03.stl, mriya-bumper-mjf-right-v1.02.stl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]
2024-09-17 update MJF&SLA cases
    [mriya-bumper-mjf-left-v1.05.stl, mriya-bumper-mjf-left-v1.06.stl, mriya-bumper-mjf-right-v1.05.stl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]
2024-09-22 update bumper cases
    [mriya-bumper-fdm-left-v1.08.stl, mriya-bumper-fdm-left-v1.09.stl, mriya-bumper-fdm-right-v1.08.stl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]
2024-10-31 update FDM classic case
    [mriya-classic-fdm-left-v1.05.stl, mriya-classic-fdm-left-v1.06.stl, mriya-classic-fdm-right-v1.05.stl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]
2025-01-19 update PCB renders
2025-03-17 update CNC plates
    [mriya-cnc-bottom-plate-v.1.00.f3d, mriya-cnc-bottom-plate-v.1.00.step, mriya-cnc-bottom-plate.f3d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]
2025-04-25 update MJF bumper case
    [mriya-bumper-mjf-left-v1.15.stl, mriya-bumper-mjf-right-v1.15.stl, mriya-bumper-mjf-v1.15.f3d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]
2025-04-30 update BOM
2025-11-23 update case files
    [mriya-bumper-fdm-left-v1.14.stl, mriya-bumper-fdm-right-v1.14.stl, mriya-bumper-fdm-v1.14.f3d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]
2025-12-15 add gerbers
    [(Unsaved).f3d, mriya-cnc-bottom-plate-v.1.00.f3d, mriya-cnc-bottom-plate-v.1.00.step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]
2026-02-08 add kicad files
    [(Unsaved).f3d, 12-Pin Header - Female - 2.54mm.step, 5-Pin Header - Female - 2.54mm.step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]
